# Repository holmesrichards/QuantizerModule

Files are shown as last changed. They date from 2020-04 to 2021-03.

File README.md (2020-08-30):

# QuantizerModule
Code and hardware for Kosmo/Eurorack quantizer module

This is a dual quantizer based on the [dac/ino](https://github.com/holmesrichards/dac_ino) board. As such it uses the dac\_ino library as well as the Quantizer library in this repository. 

Design is for Kosmo format module but the PCB and code would work equally well for a Eurorack version if the board were mounted perpendicular to the panel. It would just need a smaller front panel. Likewise with perpendicular mounting it could be a smaller single Kosmo quantizer.

## Front panel
On the front panel, for each quantizer section, are:

- CV1 and CV2 inputs
- Quantize gate input
- Trigger input
- CV output
- CV2 attenuator
- Quantize toggle switch
- Scale selection 12 position rotary switch
- Bank selection 6 position switch

## Use
The control voltage to be quantized is plugged into CV1. It should be in the range 0–5 volts, though voltages outside this range (within reason) shouldn't cause damage.

CV2 is an offset; it is added to the quantized CV1 to produce the output. It should also be in the range 0–5 volts. It can be attenuated with the knob. Normalled value is 5 volts before attenuation.

The Quantize switch can be used to disable quantization, in which case the output CV is just CV1 + CV2 (attenuated). If the Quantize switch is on and a gate source is plugged into the Quantize input, quantization is on only when the gate is on. If nothing is plugged in and the Quantize switch is on, quantization is on.

If nothing is plugged into the Trigger input, the input control voltages are sampled and the output control voltage is updated continually. If a trigger or gate source is plugged in, updating occurs only when a trigger or gate is present. In that case the module behaves like a quantizing (or not, if quantizing is off) sample and hold.

The rotary switches are used to select a bank of scales and a scale within that bank. There can be up to 12 scales stored in each of up to 6 banks, which makes 72 scales for those of you who've lost your calculator. ("Up to." Depending on the scales, 72 of them might exceed the Arduino's program memory capacity.) See [scales document](./docs/SCALES.md) for the scales built into the software as supplied. If you want other scales it's easy enough to change them. There's a mechanism to convert Scala format scale files, or definitions in terms of equal divisions of the octave or generators and periods into data for the Quantizer library. See [change scale instructions](./docs/CHANGESCALES.md).

## Current requirements
28 mA +12 V  
 4 mA -12 V

## Building
For build notes see [here](docs/BUILD.md).

## Software
A sketch and two libraries are required:

- [QuantSketch.ino](software/QuantSketch/QuantSketch.ino)
- [Quantizer library](software/Quantizer) (.cpp and .h files)
- [dac/ino library](https://github.com/holmesrichards/dac_ino/tree/master/software) (.cpp and .h files)

But the dac_ino library itself uses three libraries:

- Arduino, which is standard (built in to the IDE)
- SPI, which I think is also built in to the IDE
- DirectIO, from here: https://github.com/mmarchetti/DirectIO.git For this you apparently just need DirectIO.h, there is no .cpp file.

On my system (Linux, off-line Arduino IDE) the non standard libraries are in sub-folders, named Quantizer, dac_ino, and DirectIO, of the ~/Arduino/libraries folder. QuantSketch.ino can be anywhere though the IDE wants it to be inside a folder called QuantSketch. For details and other platforms and IDEs, consult Arduino documentation.

## Credits
The Quantizer library and the table building script are based on work by Brendon Cassidy, see https://github.com/bpcmusic/telex and https://github.com/bpcmusic/telex_scales .

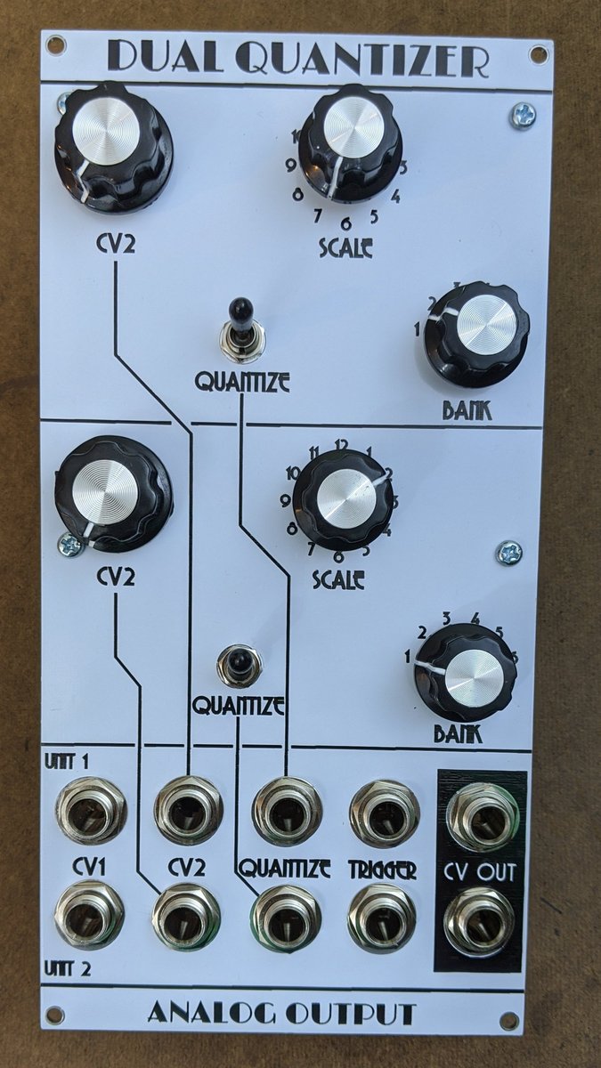
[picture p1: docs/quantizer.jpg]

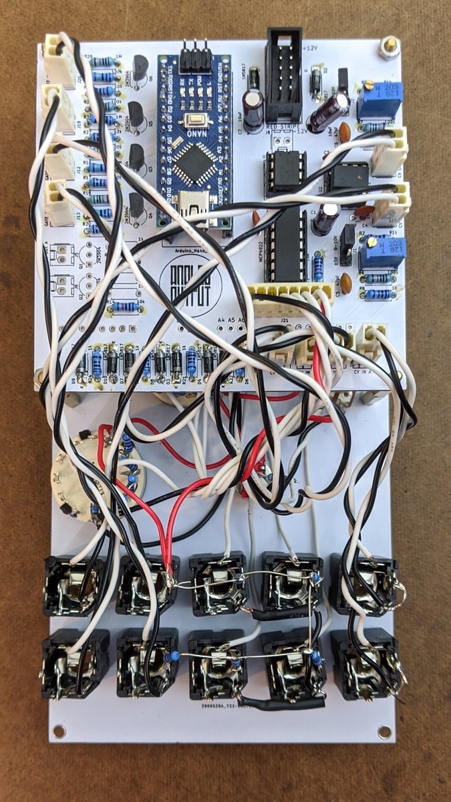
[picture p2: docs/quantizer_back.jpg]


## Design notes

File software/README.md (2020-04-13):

# Quantizer software

Based on:

Quantizer.cpp and Quantizer.h from https://github.com/bpcmusic/telex/tree/master/software/TELEXo

table\_builder.py from https://github.com/bpcmusic/telex_scales

Here is the README from the latter:

># telex_scales
>scale generator for the TELEX modules
>
>This is a simple python script to allow the conversion of Scala scales into the TELEX format. Please be kind - it is ugly and was done quite quickly.
>
>Here are some steps to use it:
>
>1. Put some Scala scales in a subdirector (I used "scl/" and found them at the Scala site: http://www.huygens-fokker.org/docs/scales.zip).
>2. Reference the scales that you want in the order that you want in a text file; see "items.txt" for and example.
>3. Run the "table_builder.py" script and reference your input file. For example: python table_builder.py -i items.txt
>4. The script will output a "scales.cpp" file in your current directory.
>5. Cut and paste the two parts of the output into the corresponding areas of the "Quantizer.cpp" and the "Quantizer.h" files in your Arduino project directory for the TELEX.
>6. Deploy your updated code to your TELEX's teensy.
>
>Hope it works for you!

In this directory:

- Original — TELEXo version this is based on
- Quantizer — Modified library
- scl — Uh oh, you see this directory? Git was supposed to ignore it. Sheesh.
- items.txt — Input for table_builder.py
- QuantSketch.ino – Arduino sketch for the quantizer module
- README.md – You're reading me
- scales.cpp – Output from table_builder.py
- scindex.py — Python script to make an index of the scl directory
- table_builder.py – Python script to generate data for Quantizer

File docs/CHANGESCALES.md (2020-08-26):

# Changing Dual Quantizer scales

If you want to create your own scales or scale sets here is how.

Go into the software directory and create a text file containing a description of your scale set. You can use common\_scales.txt or esoteric\_scales.txt as a starting point if you want. The syntax is as follows. 

Each command or scale description is on a new line. Things in &lt;anglebrackets&gt; are to be replaced with whatever value you want. Things in [square brackets] are optional.

Each scale can be given a description, which can be any text you want; it appears only in comments in the table\_builder output.

## Commands
In the absence of commands to the contrary each scale is assigned
to be the next scale in the same bank as the previous; first scale is
bank 1 (index 0), scale 1 (index 0)

Use commands to change this sequence:
<dl>
<dt>+b &lt;bank&gt; [#&lt;description&gt;]</dt>
<dd>Append next scale to bank #&lt;bank&gt; (index &lt;bank&gt;-1) with given description. Description overwrites previous description if given.</dd>

<dt>+s &lt;scale&gt; </dt>
<dd>Assign next scale to scale number &lt;scale&gt; (index &lt;scale&gt;-1) in the current bank.</dd>

<dt>+d &lt;bank1&gt; &lt;scale1&gt; &lt;bank2&gt; &lt;scale2&gt;</dt>
<dd>Duplicate scale at bank &lt;bank1&gt;, scale &lt;scale1&gt; to bank &lt;bank2&gt;, scale &lt;scale2&gt;. (Dupicate entries are made in the bank/scale table, but the scale data itself is not duplicated.)</dd>
</dt>
</dl>

## Scale descriptors
A scale descriptor can be one of:

<dl>
<dt>&lt;path to scl file&gt; [#&lt;description&gt;]</dt>
<dd>Scale is described in Scala format file. Description if present overrides the description in the file.</dd>

<dt>+g &lt;n&gt; &lt;generator&gt; [&lt;period&gt;] [&lt;firstnote&gt;] [#&lt;description&gt;]</dt>
<dd>Generate a scale with &lt;n&gt; notes using generator &lt;generator&gt; and period &lt;period&gt; starting from first note &lt;firstnote&gt;. Parameters can be ratios or cents. E.g.:<br>
+g 12 3/2 2/1 500<br>
for a 12-tone Pythagorean scale starting at 500 cents above the 0 volt note.  If the period is omitted, 2/1 is the default. If first note is omitted, 0 is the default.</dd>

<dt>+e &lt;n&gt; [list of numbers] [#&lt;description&gt;]</dt>
<dd>Generate a scale using the listed entries (indexed from 0) from an &lt;n&gt;-equal division of the octave. E.g.:<br>
+e 12 0 2 4 5 7 9 11<br>
for a 12-equal major scale. If the list is omitted, the scale contains all
n notes.</dd>

<dt>+q &lt;n&gt; &lt;period&gt; [list of numbers] [#&lt;description&gt;]</dt>
<dd>Same as +e except a period to be equally divided is given. E.g.:<br>
+q 13 3/1<br>
for Bohlen-Pierce equal temperament.
</dd>
</dl>

## Table generation
Once you have your description file, feed it to table\_builder.py:

    ./table_builder -i <path>;

where &lt;path&gt; is the file path to your description file. Assuming there are no errors, the script will create an output file with the same name but file extension .cpp, containing some c++ code.

Back up your copies of Quantizer/Quantizer.cpp and Quantizer/Quantizer.h. In a text editor, open Quantizer/Quantizer.cpp. Find the line

    // INSERT AUTOGENERATED SCALE CLASS DATA HERE

and delete everything after that and before

    // END AUTOGENERATED SCALE CLASS DATA

and replace it with the lines from your .cpp output file from the beginning to before

    // for protected header

and save.

Then in a text editor, open Quantizer/Quantizer.h. Find the line

    // INSERT AUTOGENERATED SCALE HEADER DATA HERE

and delete everything after that and before

    // END AUTOGENERATED SCALE HEADER DATA

and replace it with the lines from your .cpp output file from after

    // for protected header

to the end and save.

You now have a customized version of the Quantizer library with your scales. Use it instead of the original version.

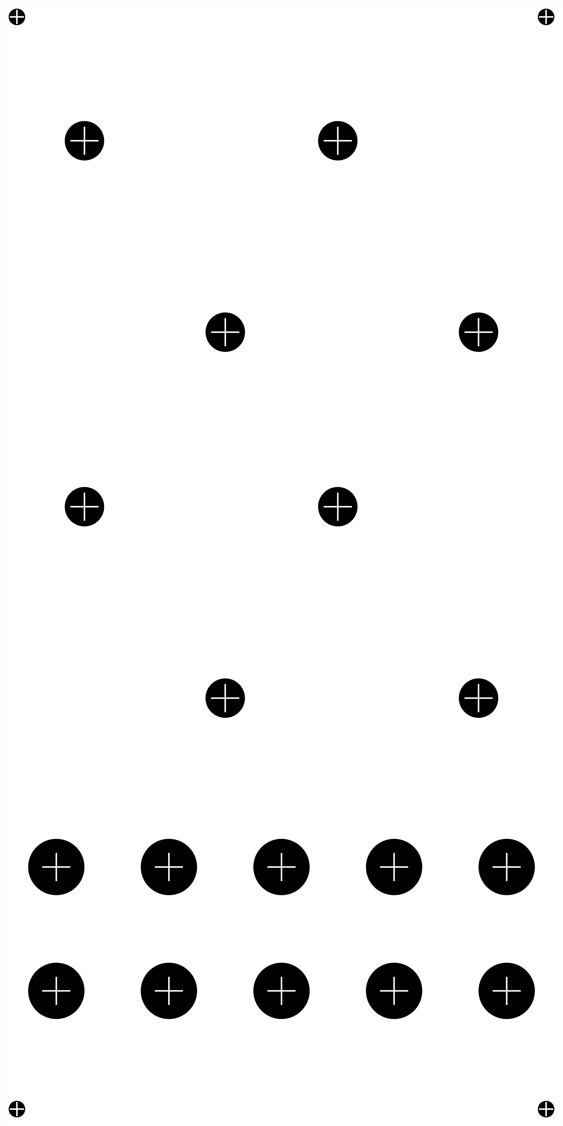
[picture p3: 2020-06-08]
hardware/Panel/Quantizer panel holes.png

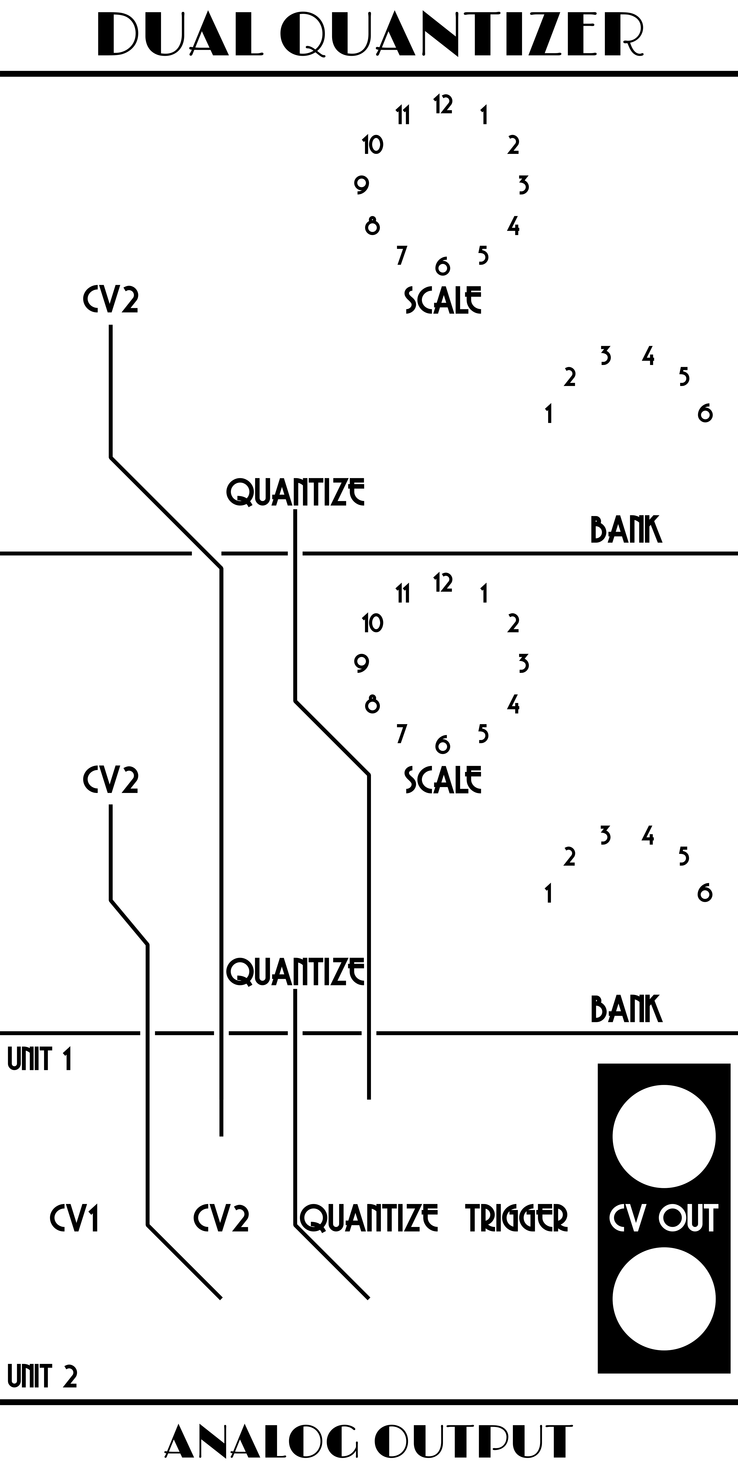
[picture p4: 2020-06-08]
hardware/Panel/Quantizer panel art.png

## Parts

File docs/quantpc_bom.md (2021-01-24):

# quantpc BOM

Sun 24 Jan 2021 08:23:08 AM EST

Generated from schematic by Eeschema 5.1.6-c6e7f7d~87~ubuntu20.04.1

These are components in addition to those needed for the dac/ino board.

**Component Count:** 69

| Value | Qty | Part | Description | Vendor |
| ----- | --- | ---- | --- | --- |
| J101, J102, J103, J104, J105, J106, J107, J108, J109, J112 | 10 | MOLEX 2 PIN | 2 pin Molex connector | Tayda A-826 |
| J110, J111, J114, J115, J116, J117, J118, J119, J120, J121 | 10 | AudioJack2_SwitchT | Audio Jack, 2 Poles (Mono / TS), Switched T Pole (Normalling) | Tayda A-1121 |
| J113 | 1 | MOLEX 8 PIN | 8 pin Molex connector | Tayda A-832 |
| R101, R102, R103, R104, R105, R106, R107, R108, R109, R110, R111, R112, R113, R114, R115, R116, R121, R122, R123, R124, R125, R126, R127, R128, R129, R130, R131, R132, R133, R134, R135, R136 | 32 | 1k | Resistor | Tayda A-2200 |
| R117, R118, R119, R137, R138, R139 | 6 | 10k | Resistor | Tayda A-2203 |
| R120, R140 | 2 | 100k | Resistor | Tayda A-2244 |
| RV101, RV102 | 2 | 100k | Linear panel mount potentiometer | Tayda A-2979 |
| SW101, SW106 | 2 | SW\_SPST | Single Pole Single Throw (SPST) switch | Tayda A-3186 |
| SW102, SW103, SW104, SW105 | 4 | SW_Rotary12 | rotary switch with 12 positions* | Tayda A-1893 |
  
\* Use included yoke to limit two switches to 6 positions.

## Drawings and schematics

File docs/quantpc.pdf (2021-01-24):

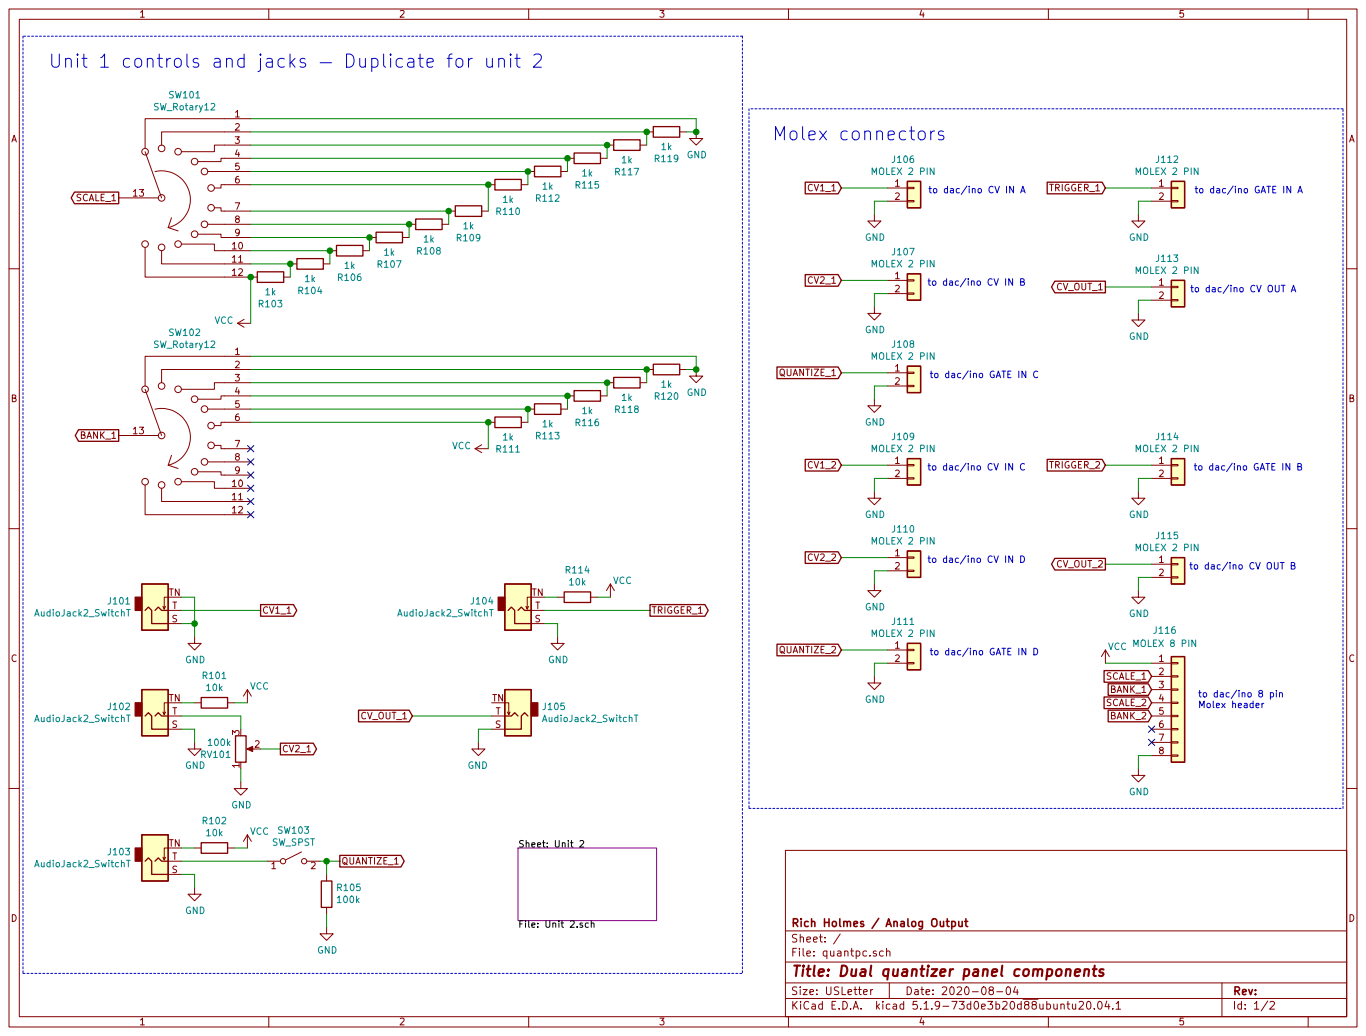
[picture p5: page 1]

to dac/ino CV IN C Unit 1 controls and jacks Duplicate for unit 2

to dac/ino 8 pin Molex header Molex connectors

to dac/ino CV IN A

to dac/ino GATE IN A

to dac/ino CV IN B

to dac/ino CV OUT A

to dac/ino GATE IN C

to dac/ino GATE IN B

to dac/ino CV OUT B

to dac/ino GATE IN D

File: quantpc.sch Sheet: / Rich Holmes / Analog Output Sheet: Unit 2 File: Unit 2.sch GND

Id: 1/2 Title: Dual quantizer panel components

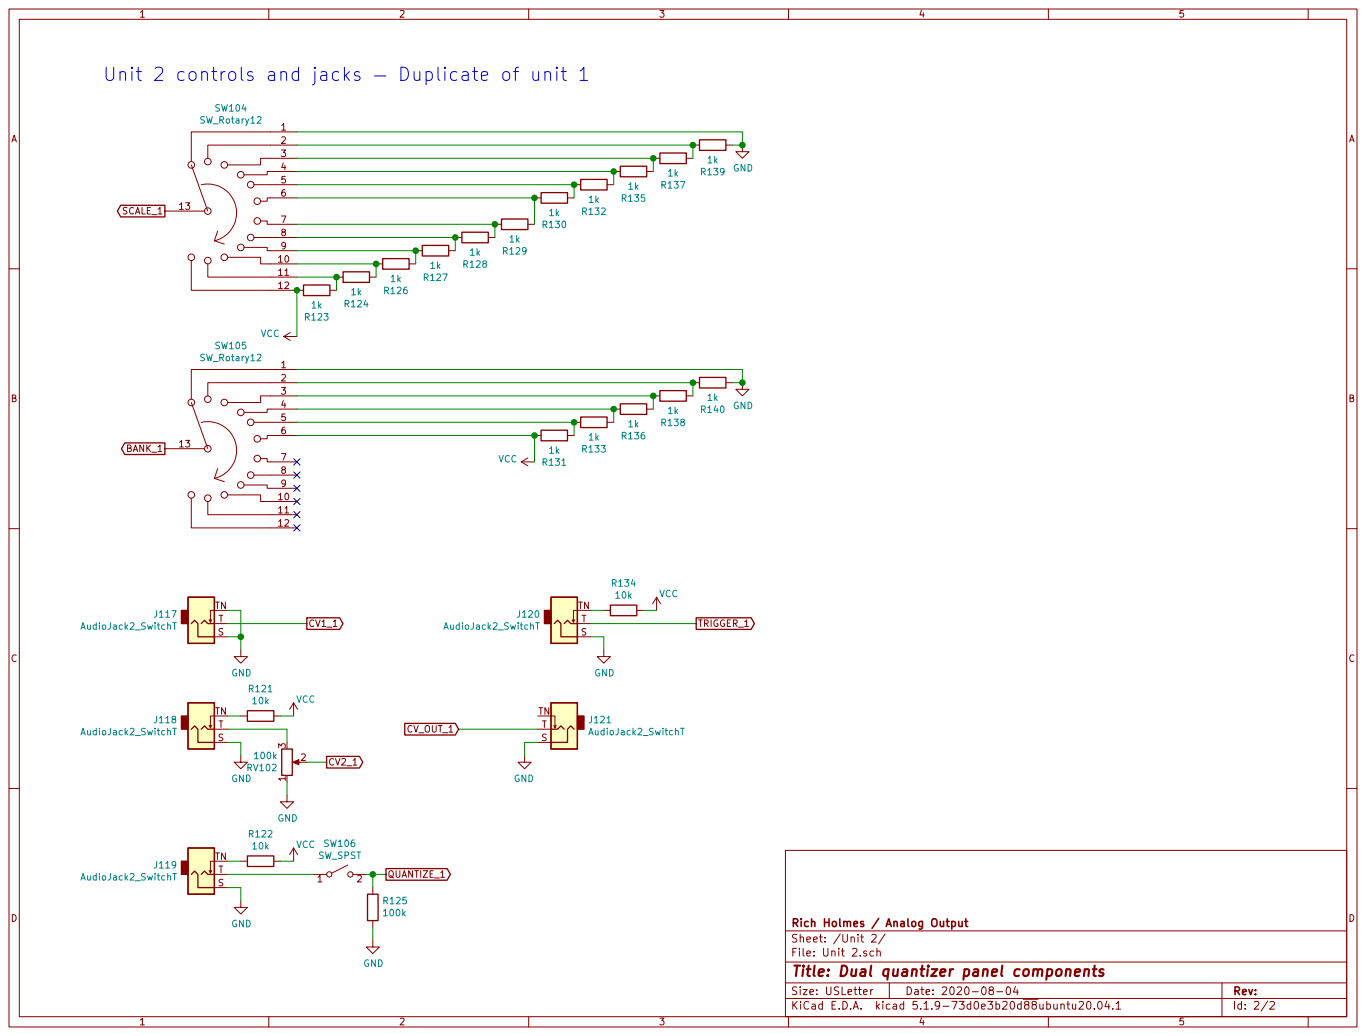
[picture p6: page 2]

100k GND
File: Unit 2.sch Sheet: /Unit 2/ Rich Holmes / Analog Output GND

Id: 2/2 Title: Dual quantizer panel components

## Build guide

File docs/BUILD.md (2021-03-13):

# Dual Quantizer Build Notes

## dac/ino build information
Current version uses v1.3 release of the [dac/ino](https://github.com/holmesrichards/dac_ino) board. See that repository for general building information.

**Note that the dac/ino schematic (for the board) and the Quantizer schematic (for the panel components) are two separate things. Component references below are to the dac/ino board, *not* the Quantizer panel. **

Dual Quantizer does not use:

* Gate Out A and B
* All pin headers (aside from 3-pin jumper headers)
* VCC/Gnd Molex header

so these dac/ino components can be omitted: Q1, Q2, R10–13 (don't omit R14!), J5–J8, J10, J11, J14

dac/ino CV outputs can range 0–10V or ±5V. Set jumpers for 0–10V outputs. Since CV1 is limited to 0–5V, the quantized CV1 will also be limited to about 0–5V, but the CV2 offset can change the output range up to 5–10V. If desired you can omit J1 and J2 in favor of hardwired jumpers.

Use 35 mm spacers to mount dac/ino board to the panel after wiring is done.

## Quantizer panel

Mount panel components to the panel, then wire (referring to [panel components schematic](./quantpc.pdf)):

* CV1 In tip normal pins to sleeve pins. Connect sleeve and tip pins to 2-pin Molex connectors to CV In A and C on the dac/ino board (ground is on the right side of the Molex header as viewed from the tab side).
* CV2 In tip pins to pin 3 on the attenuators. Connect sleeves to ground. 
* Quantize tip to bottom terminals of toggle switches. Connect sleeves to ground. 
* Trigger tips and sleeves to Molex connectors to Gate In A and B.
* CV Out tips to Molex connectors to CV Out A and B.
* 10k resistor from tip normal pin to VCC on each of the CV2, Quantize, and Trigger jacks. VCC is on pin 8 of 8 pin Molex connector.
* 100k resistor on middle terminal of each toggle. Other end of resistor to 2-pin Molex ground side. Middle terminal to 2-pin Molex other side. 2-pin Molex to Gate In C and D. Toggle top terminals are not connected.
* Attenuator pins 1 and 2 to a 2-pin Molex connector (pin 1 is ground) to CV In B and D.
* On Scale rotary switches, add 11 1k resistors between pins 1–2, 2–3, 3–4, … 11–12. Wire center pin to 8 pin Molex as shown in circuit diagram. Connect pin 1 to ground and pin 12 to VCC from 8 pin Molex. 
* On Bank rotary switches, add 5 1k resistors between pins 1–2, 2–3, 3–4, 4–5, 5–6. Wire center pin to 8 pin Molex as shown in circuit diagram. Connect pin 1 to ground and 6 to VCC from 8 pin Molex. 

Here's a diagram (by Dud):
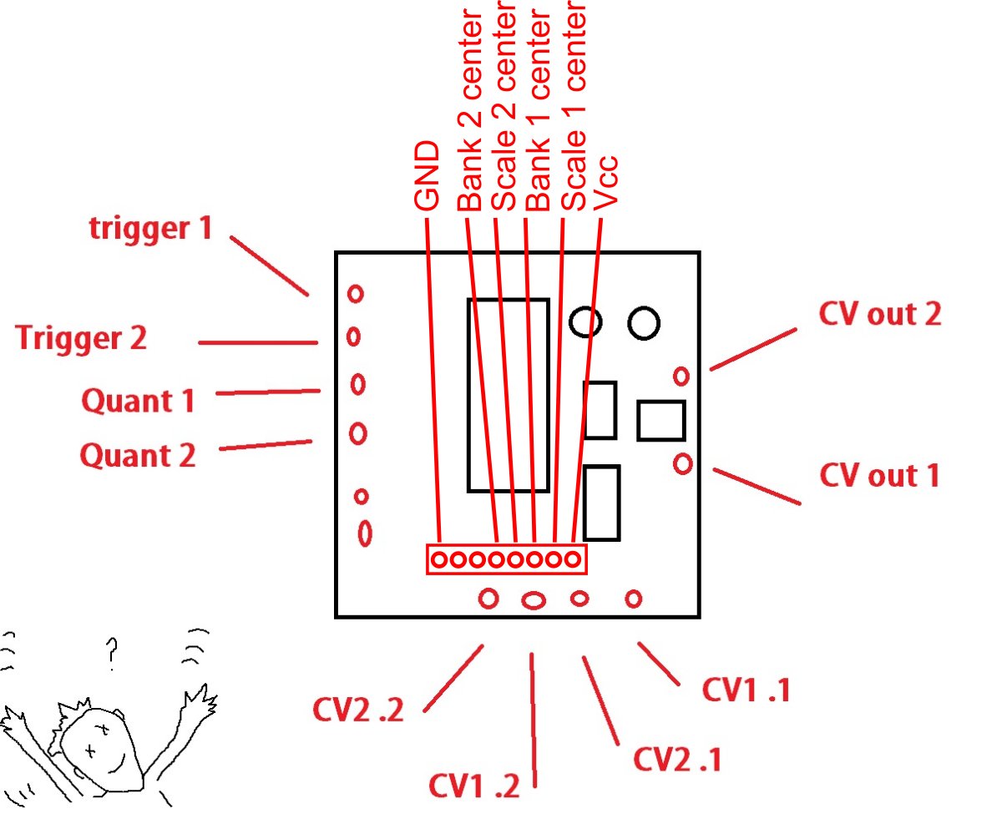
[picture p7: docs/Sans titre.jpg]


Here's a photo where you can kind of see the rotary switches:
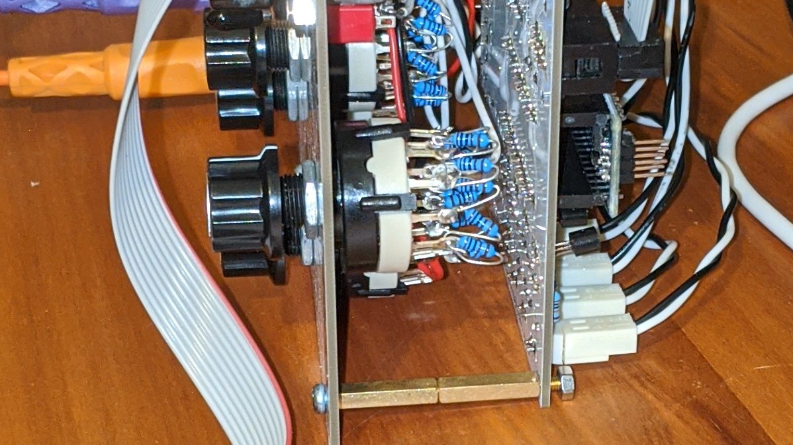
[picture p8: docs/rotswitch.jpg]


8 pin Molex connections are, from left to right:

1 Ground
2 Not connected
3 Not connected
4 Bank 2 switch center pin
5 Scale 2 switch center pin
6 Bank 1 switch center pin
7 Scale 1 switch center pin
8 Vcc

Wiring photo: (Black wires are ground, red are Vcc, white others are signals)


BOM for the panel components is [here](quantpc_bom.md).

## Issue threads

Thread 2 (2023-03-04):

dac_ino.h Documentation Issue

JamesLPearson, 2023-03-04:
Hi Rich,

A very minor issue that I thought I should point out because it confused me for a while. I was modifying your Quantizer module solution (thanks very much again for the excellent work on this!) to add a pulse output (basically just a copy of a clock/gate/trigger input. I have used two of the Gate Outputs and I've used the function:

`void writeGate(GateOutChannel channel_, bool state_);`

from dac_ino.

However, in **dac_ino.h** the definition doesn't seem to match the implementation:
```
  //! Write to a gate output channel
  /*!
    \param channel_  The selected output channel
    \param state_    The logical state (true = HIGH, false = LOW)
  */
  void writeGate(GateOutChannel channel_, bool state_);
```

Here is the code from **dac_ino.cpp**:

```
void dac_ino::writeGate(GateOutChannel channel_, bool state_)
{
  switch (channel_)
  {
    case GateOutChannel::A:
    {
#if defined __AVR__
      m_outputGateA = state_ ? LOW : HIGH;
#else
      digitalWrite(k_pinGateOutA, (state_ ? LOW : HIGH));
#endif

      break;
    }

```
It looks like true = LOW and false = HIGH?

Or do I have this wrong? After checking my output with a scope I had to reverse the boolean values.

Thanks again!
James

holmesrichards, 2023-03-04:
Thanks — not sure what to tell you. The software is adapted from
https://github.com/shaduzlabs/synapse and those lines come straight from
there. I don't use writeGate in the quantizer software but I have used it
in
https://github.com/holmesrichards/ribcon/blob/main/Software/ribcon/ribcon.ino
and it's true = gate on, false = gate off. And it does work as expected.

In dac_ino.cpp, writeGate sends LOW if state_ is true else HIGH, and that
should be right because the output at the microcontroller pin is inverted
by the transistor buffer on the board. So state_ = true should result in
gate on and _false should give gate off. I think the dac_ino.h comment is
correct if you consider it to be describing the gate at the board output,
not at the microcontroller pin.

On Sat, Mar 4, 2023 at 10:47 AM JamesLPearson ***@***.***>
wrote:

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

--
Rich Holmes

***@***.***
https://about.me/richholmes

JamesLPearson, 2023-03-04:
Hi Rich,

That's it; you've cracked it for me, thank you. I didn't buffer the the output with a transistor and so it's not being inverted! That explains my issue/confusion. I think I should probably add in a transistor buffer now... :)

Thank you - issue (should be) resolved!

JamesLPearson, 2023-03-04:
Yup, that fixed the issue and now I have a safer Arduino with the buffered outputs :)

Thanks again.

Closed 2023-03-04.

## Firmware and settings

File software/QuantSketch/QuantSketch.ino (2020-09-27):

/*

Dual Quantizer
Rich Holmes 4/2020

Uses dac_ino library to communicate with board and quantize library
to do the quantization, this is just the glue in between...

 */

#include <dac_ino.h>
#include <Quantizer.h>

//  0 - 4095  = 0 - 5V
//  0 - 819   = 0 - 1V
//  68.25 = 1V / 12

#define OCTAVE (4095 / 5)
#define NOTE (OCTAVE / 12)
#define DEBUG false

using namespace dcrd;

Quantizer q[2];

dac_ino::CVInChannel   cv1InChan[2] = {dac_ino::CVInChannel::A, dac_ino::CVInChannel::C};
dac_ino::CVInChannel   cv2InChan[2] = {dac_ino::CVInChannel::B, dac_ino::CVInChannel::D};
dac_ino::CVInChannel   scaleChan[2] = {dac_ino::CVInChannel::H, dac_ino::CVInChannel::F};
dac_ino::CVInChannel   bankChan[2] = {dac_ino::CVInChannel::G, dac_ino::CVInChannel::E};
dac_ino::CVOutChannel  cvOutChan[2] = {dac_ino::CVOutChannel::A, dac_ino::CVOutChannel::B};

dac_ino::GateInChannel quantInChan[2] = {dac_ino::GateInChannel::C, dac_ino::GateInChannel::D};
dac_ino::GateInChannel trigChan[2] = {dac_ino::GateInChannel::A, dac_ino::GateInChannel::B};

bool triggered[2] = {false, false};

unsigned cv[2]; // the CV before quantization
unsigned cvq; // the CV after quantization
unsigned cv2[2]; // transposition CV
unsigned rsbank[2]; // rotary switch states
unsigned rsscale[2]; // rotary switch states
bool     qgate[2]; // quantization gate/switch
unsigned bank[2] = {0, 0};  // scale banks in use
unsigned scale[2] = {0, 0}; // scales in use

#if DEBUG
unsigned cvold[2] = {9999, 9999}; // previous unquantized CV
unsigned cv2old[2] = {9999, 9999}; // previous transposition CV
unsigned bankold[2] = {9999, 9999}; // previous bank
unsigned scaleold[2] = {9999, 9999}; // previous scale
#endif

// For bank switch there are 6 positions (0 to 5) separated with
// 4 resistors
//
//  GND --0--/\/\/\/--1--/\/\/\/.../\/\/\/--5--VCC
//
// So expect to read values 0, 1023/5, 2*1023/5, ... 1023
//
// or in reality 0 is between 0 and 1023/10, 2 is between
// 1023/10 and 3*1023/10, etc.
// Similarly for scale switch with 12 positions

unsigned bankBins[6] = {102, 307, 512, 716, 921, 1024};
unsigned scaleBins[12] = {47, 140, 233, 326, 419, 512,
			  605, 698, 791, 884, 977, 1024};

void onTrig0RisingEdge();
void onTrig1RisingEdge();

void setup()
{
#if DEBUG
  Serial.begin(9600);
#endif
  dac_inoBoard.begin();
  q[0].SetScale (bank[0], scale[0]);
  q[1].SetScale (bank[1], scale[1]);

  // Set up trigger interrupts
  dac_inoBoard.gateInputInterrupt
    (
     trigChan[0],
     onTrig0RisingEdge,
     dac_ino::GateInterrupt::RisingEdge
     );
  dac_inoBoard.gateInputInterrupt
    (
     trigChan[1],
     onTrig1RisingEdge,
     dac_ino::GateInterrupt::RisingEdge
     );
}

void loop()
{
  // do all this for both quantizers
  
  for (unsigned iq = 0; iq < 2; ++iq)
    {
#if DEBUG
      if (triggered[iq])
	{
	    // There was an interrupt
	    Serial.print ("Oh hey trigger ");
	    Serial.println (iq);
	}
#endif
	  
      // Proceed only IF trigger is on now (which happens if we've
      // input a trigger or if there's nothing plugged into the
      // trigger) or if there's an unhandled interrupt
	  
      if (triggered[iq] || dac_inoBoard.readGate(trigChan[iq]))
	{
	  // Read the rotary switches
	  rsbank[iq] = dac_inoBoard.readCV(bankChan[iq]);
	  rsscale[iq] = dac_inoBoard.readCV(scaleChan[iq]);
	  // Get CV, convert to 11 bits
	  cv[iq] = 2.0 * dac_inoBoard.readCV(cv1InChan[iq]);
	  cv2[iq] = 2.0 * dac_inoBoard.readCV(cv2InChan[iq]);
	  // Check the quantization gate/switch
	  qgate[iq] = dac_inoBoard.readGate(quantInChan[iq]);
	  
	  // Use the rotary switches to determine the banks and scales
      
	  for (unsigned i = 0; i < 6; ++i)
	    if (rsbank[iq] < bankBins[i])
	      {
		rsbank[iq] = i;
		break;
	      }
      
	  for (unsigned i = 0; i < 12; ++i)
	    if (rsscale[iq] < scaleBins[i])
	      {
		rsscale[iq] = i;
		break;
	      }
      
	  if (rsbank[iq] != bank[iq] || rsscale[iq] != scale[iq])
	    {
	      bank[iq] = rsbank[iq];
	      scale[iq] = rsscale[iq];
	      q[iq].SetScale (bank[iq], scale[iq]);
#if DEBUG
	      Serial.print ("Set quantizer "); Serial.print(iq);
	      Serial.print (" bank "); Serial.print (bank[iq]);
	      Serial.print (" scale "); Serial.println (scale[iq]);
#endif
	    }

	  // Quantize the CV but only IF quantize gate is on
	  // which happens if [we've input a gate or there's
	  // nothing plugged into the gate], and [the toggle switch
	  // is on]
    int qq = qgate[iq] ? q[iq].Quantize(cv[iq]).Value : cv[iq];
    if (qq >= 0 && qq <= 4095)
    {
	    cvq = qq + cv2[iq];
      // Send it out
	    dac_inoBoard.writeCV(cvOutChan[iq], cvq);
    
#if DEBUG
  	  if (abs(int(cv[iq])-int(cvold[iq])) > 10 || abs(int(cv2[iq])-int(cv2old[iq])) > 10
  	  || bank[iq] != bankold[iq] || scale[iq] != scaleold[iq])
  	    {
  	      Serial.print ("Quantizer "); Serial.print (iq);
  	      Serial.print (" CV1 in = "); Serial.print (cv[iq]);
  	      Serial.print (" bank "); Serial.print (bank[iq]);
  	      Serial.print (" scale "); Serial.print (scale[iq]);
          Serial.print (" quantize "); Serial.print (qgate[iq]);
	        Serial.print (" CV2 in = "); Serial.print (cv2[iq]);
	        Serial.print (" CV out = "); Serial.println (cvq);

	        cvold[iq] = cv[iq];
          cv2old[iq] = cv2[iq];
          bankold[iq] = bank[iq];
          scaleold[iq] = scale[iq];
	      }
#endif
    }
	}
      triggered[iq] = false;
    } // end loop over quantizers
      
  // Take a break, you've earned it
  delayMicroseconds(1000);
}

// When we see a trigger, arrange for quantization ASAP
void onTrig0RisingEdge()
{
  triggered[0] = true;
}

void onTrig1RisingEdge()
{
  triggered[1] = true;
}

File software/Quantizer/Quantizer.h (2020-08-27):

/*
 * Quantizer library
 * Rich Holmes
 * 
 * Based on:
 * =======
 * TELEXo Eurorack Module
 * (c) 2016 Brendon Cassidy
 * MIT License
 * =======
 *
 * Mods include:
 * Get rid of frequency stuff, we don't need it. Can always calculate it
 * from Value anyway.
 *
 * Use avr/pgmspace to put scale data in program space, saving
 * dynamic memory.
 *
 */
 
#ifndef Quantizer_h
#define Quantizer_h

#include "Arduino.h"
#include <avr/pgmspace.h>

#define DACTOP 4095   // limit of DAC (2**12-1)
#define DAC1   4095   // DAC counts corresponding to defined voltage
#define V1     10    // voltage corresponding to DAC1
#define DACPEROCTAVE  (DAC1/V1)  // DAC counts per octave
#define SCALESET 0    // 0 for common scales, 1 for esoteric scales

struct QuantizeResponse {
  int Note; 
  int Value;
};

/*
 * Quantizes values 0-4095 to various tuning systems
 * some of this class is auto-generated by the associated python scripts
 */
class Quantizer
{
  public:

    Quantizer();
    Quantizer(int scale);
    QuantizeResponse Quantize(int in);
    void SetScale(int scale);
    float GetValueForNote(int note);

    // Bank and scale stuff
    Quantizer(int bank, int scale);
    void SetScale(int bank, int scale);

  protected:

    static const int PROGMEM bankandscale[6][12]; // index from bank-and-scale to scale

    // INSERT AUTOGENERATED SCALE HEADER DATA HERE
#if SCALESET == 0
const static int scaleCount = 68;
static const int *hints[68];
static const float *scales[68];
static const int notecount[68];

static const float PROGMEM scale0[61];
static const int PROGMEM hints0[61];
static const float PROGMEM scale1[36];
static const int PROGMEM hints1[36];
static const float PROGMEM scale2[36];
static const int PROGMEM hints2[36];
static const float PROGMEM scale3[36];
static const int PROGMEM hints3[36];
static const float PROGMEM scale4[26];
static const int PROGMEM hints4[26];
static const float PROGMEM scale5[26];
static const int PROGMEM hints5[26];
static const float PROGMEM scale6[31];
static const int PROGMEM hints6[31];
static const float PROGMEM scale7[31];
static const int PROGMEM hints7[31];
static const float PROGMEM scale8[16];
static const int PROGMEM hints8[16];
static const float PROGMEM scale9[16];
static const int PROGMEM hints9[16];
static const float PROGMEM scale10[21];
static const int PROGMEM hints10[21];
static const float PROGMEM scale11[21];
static const int PROGMEM hints11[21];
static const float PROGMEM scale12[36];
static const int PROGMEM hints12[36];
static const float PROGMEM scale13[37];
static const int PROGMEM hints13[37];
static const float PROGMEM scale14[36];
static const int PROGMEM hints14[36];
static const float PROGMEM scale15[37];
static const int PROGMEM hints15[37];
static const float PROGMEM scale16[36];
static const int PROGMEM hints16[36];
static const float PROGMEM scale17[37];
static const int PROGMEM hints17[37];
static const float PROGMEM scale18[36];
static const int PROGMEM hints18[36];
static const float PROGMEM scale19[36];
static const int PROGMEM hints19[36];
static const float PROGMEM scale20[37];
static const int PROGMEM hints20[37];
static const float PROGMEM scale21[36];
static const int PROGMEM hints21[36];
static const float PROGMEM scale22[37];
static const int PROGMEM hints22[37];
static const float PROGMEM scale23[36];
static const int PROGMEM hints23[36];
static const float PROGMEM scale24[37];
static const int PROGMEM hints24[37];
static const float PROGMEM scale25[37];
static const int PROGMEM hints25[37];
static const float PROGMEM scale26[36];
static const int PROGMEM hints26[36];
static const float PROGMEM scale27[36];
static const int PROGMEM hints27[36];
static const float PROGMEM scale28[37];
static const int PROGMEM hints28[37];
static const float PROGMEM scale29[36];
static const int PROGMEM hints29[36];
static const float PROGMEM scale30[37];
static const int PROGMEM hints30[37];
static const float PROGMEM scale31[36];
static const int PROGMEM hints31[36];
static const float PROGMEM scale32[36];
static const int PROGMEM hints32[36];
static const float PROGMEM scale33[37];
static const int PROGMEM hints33[37];
static const float PROGMEM scale34[36];
static const int PROGMEM hints34[36];
static const float PROGMEM scale35[36];
static const int PROGMEM hints35[36];
static const float PROGMEM scale36[37];
static const int PROGMEM hints36[37];
static const float PROGMEM scale37[36];
static const int PROGMEM hints37[36];
static const float PROGMEM scale38[37];
static const int PROGMEM hints38[37];
static const float PROGMEM scale39[36];
static const int PROGMEM hints39[36];
static const float PROGMEM scale40[37];
static const int PROGMEM hints40[37];
static const float PROGMEM scale41[36];
static const int PROGMEM hints41[36];
static const float PROGMEM scale42[37];
static const int PROGMEM hints42[37];
static const float PROGMEM scale43[36];
static const int PROGMEM hints43[36];
static const float PROGMEM scale44[36];
static const int PROGMEM hints44[36];
static const float PROGMEM scale45[37];
static const int PROGMEM hints45[37];
static const float PROGMEM scale46[27];
static const int PROGMEM hints46[27];
static const float PROGMEM scale47[27];
static const int PROGMEM hints47[27];
static const float PROGMEM scale48[26];
static const int PROGMEM hints48[26];
static const float PROGMEM scale49[27];
static const int PROGMEM hints49[27];
static const float PROGMEM scale50[26];
static const int PROGMEM hints50[26];
static const float PROGMEM scale51[27];
static const int PROGMEM hints51[27];
static const float PROGMEM scale52[27];
static const int PROGMEM hints52[27];
static const float PROGMEM scale53[26];
static const int PROGMEM hints53[26];
static const float PROGMEM scale54[27];
static const int PROGMEM hints54[27];
static const float PROGMEM scale55[26];
static const int PROGMEM hints55[26];
static const float PROGMEM scale56[27];
static const int PROGMEM hints56[27];
static const float PROGMEM scale57[32];
static const int PROGMEM hints57[32];
static const float PROGMEM scale58[31];
static const int PROGMEM hints58[31];
static const float PROGMEM scale59[32];
static const int PROGMEM hints59[32];
static const float PROGMEM scale60[32];
static const int PROGMEM hints60[32];
static const float PROGMEM scale61[31];
static const int PROGMEM hints61[31];
static const float PROGMEM scale62[31];
static const int PROGMEM hints62[31];
static const float PROGMEM scale63[31];
static const int PROGMEM hints63[31];
static const float PROGMEM scale64[32];
static const int PROGMEM hints64[32];
static const float PROGMEM scale65[31];
static const int PROGMEM hints65[31];
static const float PROGMEM scale66[32];
static const int PROGMEM hints66[32];
static const float PROGMEM scale67[32];
static const int PROGMEM hints67[32];
#else
const static int scaleCount = 66;
static const int *hints[66];
static const float *scales[66];
static const int notecount[66];
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

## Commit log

2020-06-08 First PCB version, backlog of numerous changes including daughterboard
    [Panel-B_Cu.gbr, Panel-B_Mask.gbr, Panel-B_Paste.gbr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]
2020-08-22 Lots of updates belatedly committed
    [Panel-B_Cu.gbr, Panel-B_Mask.gbr, Panel-B_Paste.gbr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]
2020-08-26 Put triggers on Gate In A and B; debug table_builder, scales files; corrected scale info into Quantizer
    [quantpc.sch]
2020-08-27 Duh, 4095 is 10 V not 5
2020-08-28 Get rid of old daughterboard stuff
    [daughterboard-B_Cu.gbr, daughterboard-B_Mask.gbr, daughterboard-B_Paste.gbr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]
2020-09-07 Fix link to panel components schematic.
2020-09-27 Update BUILD.md
    Correct "Gate" to "Trigger" and add resistor values
2021-02-02 Renumber panel components
    [Unit 2.sch, quantpc.sch]
2021-03-13 Clarify resistors on jacks and toggles
